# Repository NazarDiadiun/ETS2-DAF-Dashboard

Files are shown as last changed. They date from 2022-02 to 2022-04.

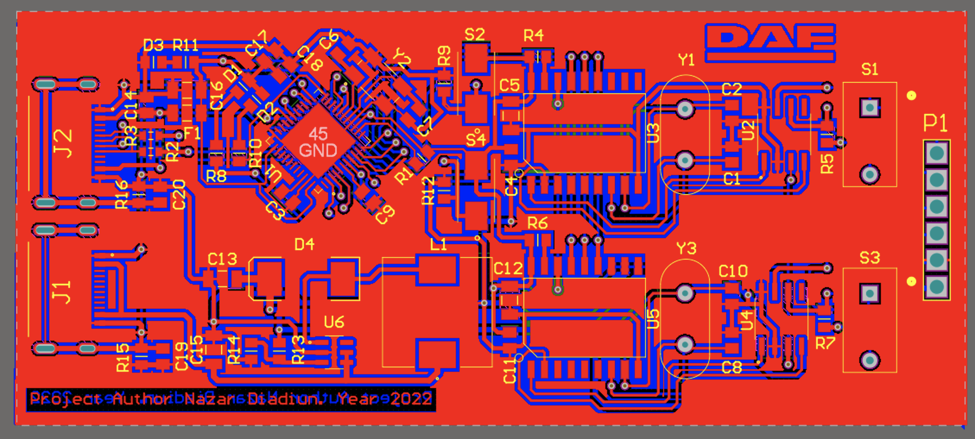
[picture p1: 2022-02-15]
Altium PCB/PCB Screenshots/PCB Front.png

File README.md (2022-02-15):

# ETS2-DAF-Dashboard

The idea of the project dates back a long time, but it was only recently that I was able to get a dashboard from a truck. As a truck fan, Euro Truck Simulator 2, and with engineering skills, I could not resist displaying telemetry from the game to the dashboard.

Gradually I will upload the project development files to share with you the experience and give the opportunity to easily repeat such project to you.

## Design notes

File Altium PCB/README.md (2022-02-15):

# PCB

The dashboard needs two CAN interfaces to function properly and fully. I decided not to invent solutions on a breadboard, but to design a printed circuit board on which I placed all the necessary components.
Project sources, archive with Gerber files, some screenshots and schematic I uploaded to this directory

## Microcontroller
The microcontroller selected ATmega32u4 as the microcontroller - it is easy to plug, supports work as a HID device and other.

## CAN Bus
CAN built on MCP2515 and TJA1050
There are switches to connect 120 Ohm resistors parallel to CAN Low and CAN High outputs

## USB
Two USB Type-C connectors are used to transfer data and power the dashboard.

## Dashboard Power
To power the dashboard it is necessary 24B, which is obtained by means of the MT3608 converter.

## Other Peripheral
Also added some buttons just in case.

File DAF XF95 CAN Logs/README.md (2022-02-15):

# CAN Bus Logs From DAF XF95

A very important part of the project was to record the logs from the truck to understand which packets to send to the dashboard.
I recorded several logs from the I-CAN bus and V-CAN bus. Both transmit data at a speed of 250KB/s.
Some work on the data packets I enclosed in the Excel files where I described what bit in the packet is responsible for.

Some very useful ones pdf files for those who are also interested in replicating the project - linked to the tachograph and its CAN bus and another - FMS standard description (commercial transport has common address for data transfer)

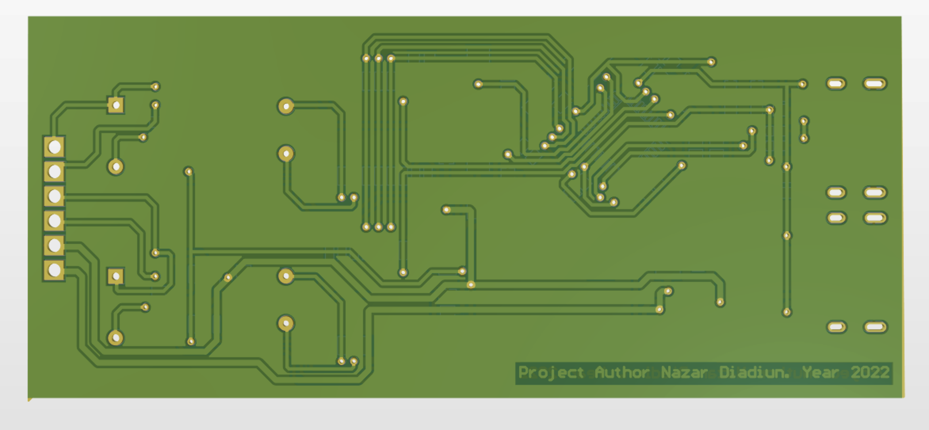
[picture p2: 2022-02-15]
Altium PCB/PCB Screenshots/PCB 3D Back.png

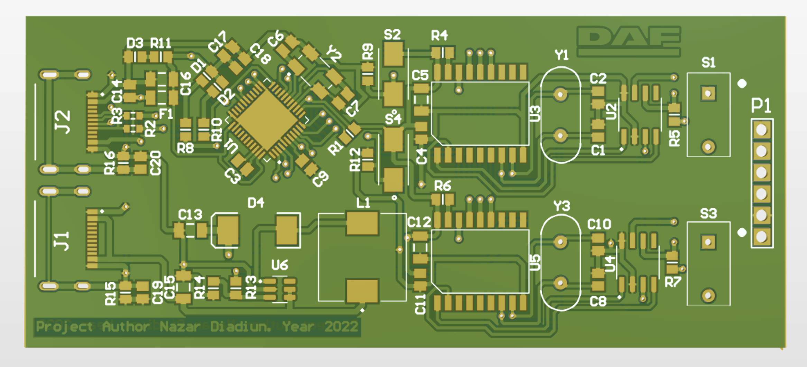
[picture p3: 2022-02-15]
Altium PCB/PCB Screenshots/PCB 3D Front.png

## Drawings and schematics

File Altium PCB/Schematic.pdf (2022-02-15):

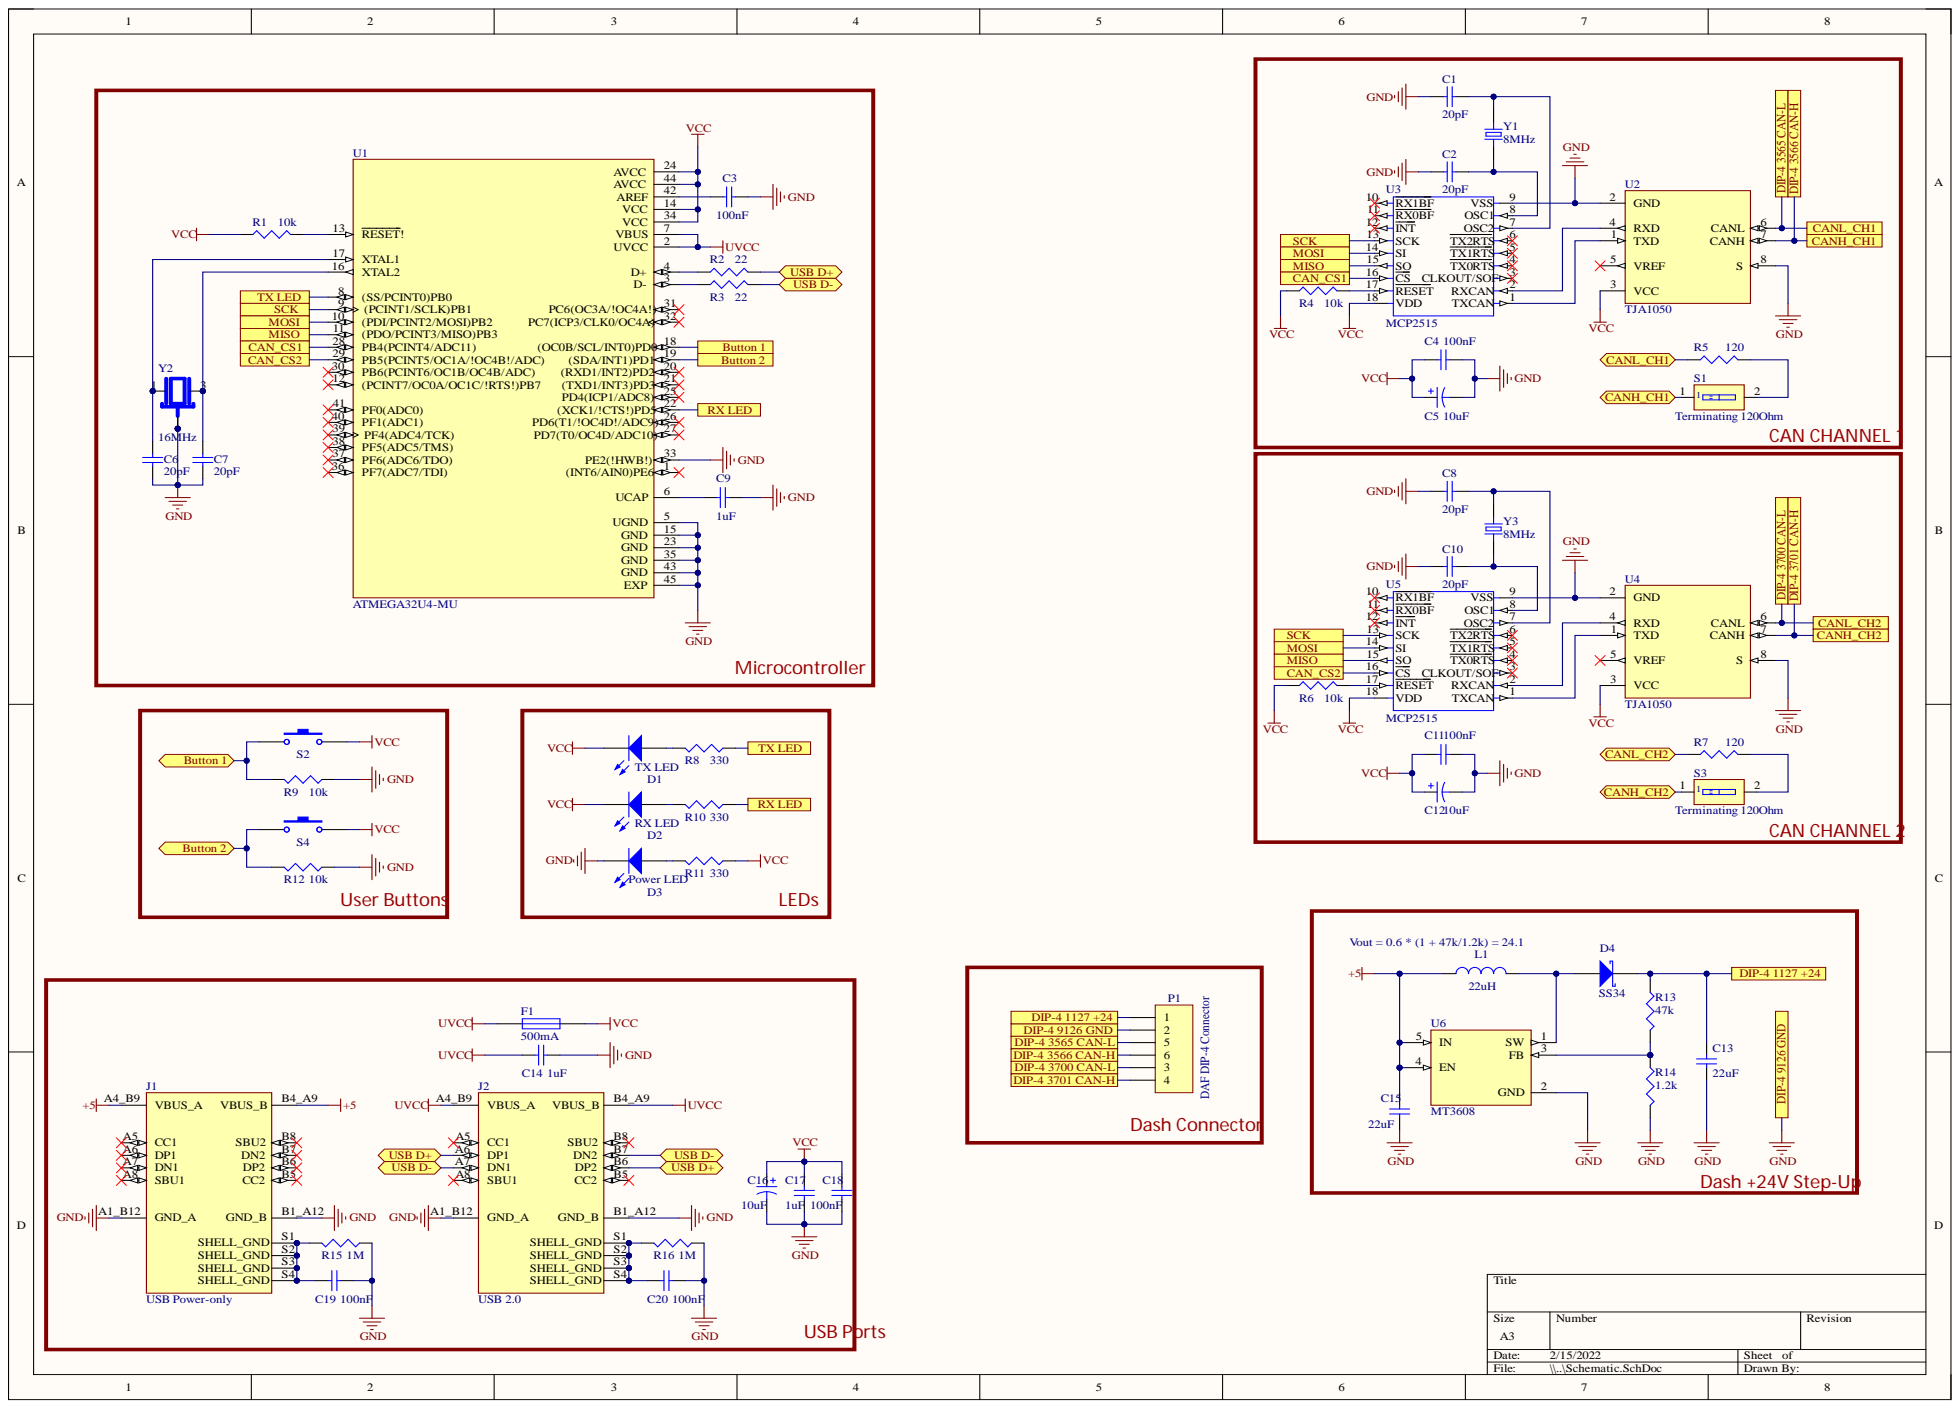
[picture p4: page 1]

DIP-4 3565 CAN-L DIP-4 3566 CAN-H DIP-4 3700 CAN-L DIP-4 3701 CAN-H

PB5(PCINT5/OC1A/!OC4B!/ADC) 29

CAN_CS2 | PB6(PCINT6/OC1B/OC4B/ADC) 30 | Button 2

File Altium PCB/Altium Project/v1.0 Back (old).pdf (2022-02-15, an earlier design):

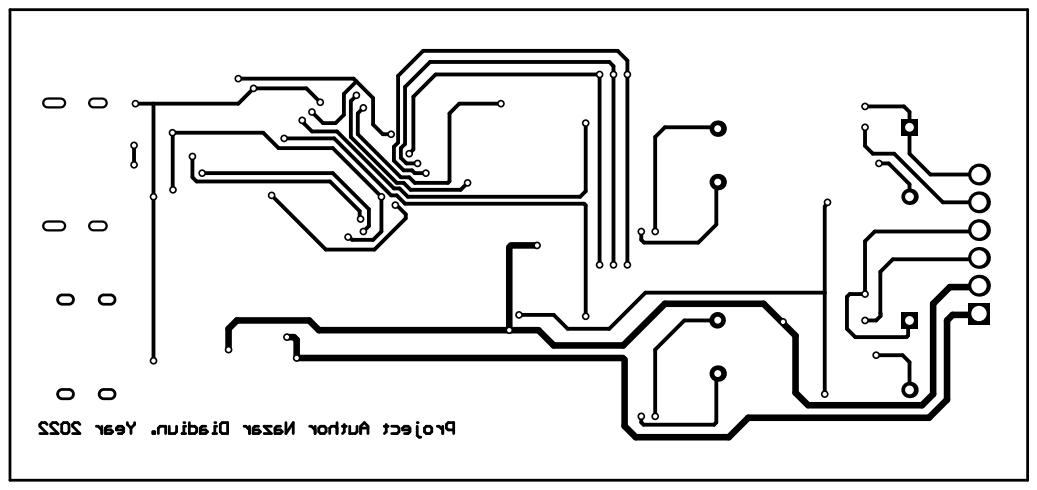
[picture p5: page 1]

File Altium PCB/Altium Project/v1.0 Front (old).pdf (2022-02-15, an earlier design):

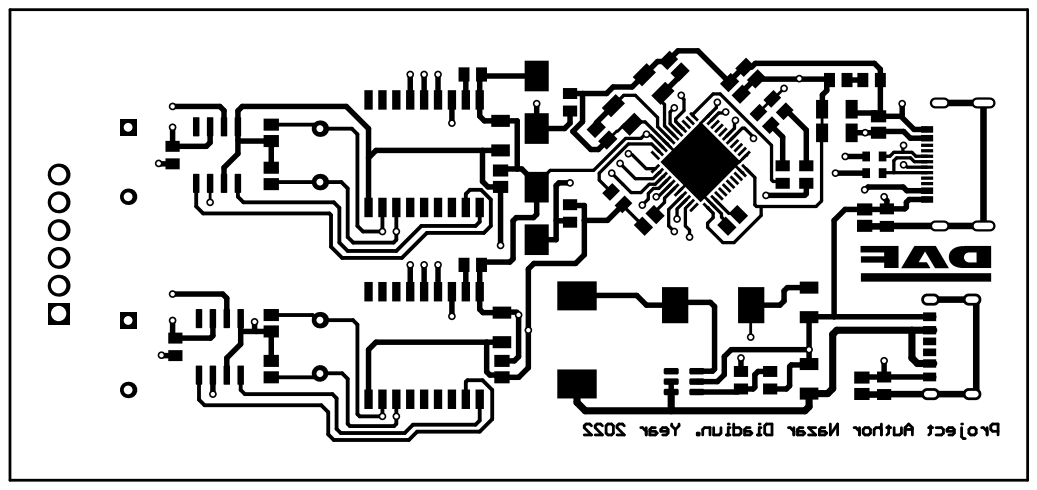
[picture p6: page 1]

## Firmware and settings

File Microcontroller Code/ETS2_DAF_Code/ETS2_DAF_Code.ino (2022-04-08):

#include <SPI.h>
#include <mcp2515.h>
#include <EEPROM.h>
#include <avr/pgmspace.h>
#include "Dashboard_Data.h"
#include "Main_Display.h"
#include "Project_Functions.h"
#include "ETS_Parse.h"

#include <TaskScheduler.h>
Scheduler DAF;

Task TS_Dashboard_Main(40, TASK_FOREVER, &Dashboard_Main_Callback);
Task TS_Right_Display(50, TASK_FOREVER, &Right_Display_Callback);
Task TS_Icons(100, TASK_FOREVER, &Icons_Callback);
Task TS_Speedometer(50, TASK_FOREVER, &Speedometer_Callback);
Task TS_RPM(50, TASK_FOREVER, &RPM_Callback);
Task TS_Distances(1000, TASK_FOREVER, &Distances_Callback);
Task TS_Arrows(50, TASK_FOREVER, &Arrows_Callback);
Task TS_Time(1000, TASK_FOREVER, &Time_Callback);
Task TS_MileageReset(500, TASK_FOREVER, &Mileage_Read_Callback);

#define I_CAN_CS 8
#define V_CAN_CS 9

MCP2515 ICAN(I_CAN_CS);
MCP2515 VCAN(V_CAN_CS);

void setup()
{
  Serial.begin(115200);
  while (!Serial) {
    ;
  }

  SPI.begin();

  ICAN.reset();
  ICAN.setBitrate(CAN_250KBPS, MCP_8MHZ);
  ICAN.setNormalMode();

  VCAN.reset();
  VCAN.setBitrate(CAN_250KBPS, MCP_8MHZ);
  VCAN.setNormalMode();




  DAF.addTask(TS_Dashboard_Main);
  TS_Dashboard_Main.enable();

  DAF.addTask(TS_Right_Display);
  TS_Right_Display.enable();

  DAF.addTask(TS_Icons);
  TS_Icons.enable();

  DAF.addTask(TS_Speedometer);
  TS_Speedometer.enable();

  DAF.addTask(TS_RPM);
  TS_RPM.enable();

  DAF.addTask(TS_Distances);
  TS_Distances.enable();

  DAF.addTask(TS_Arrows);
  TS_Arrows.enable();

  DAF.addTask(TS_Time);
  TS_Time.enable();

  DAF.addTask(TS_MileageReset);
  TS_MileageReset.enable();

  //Ignition = true;
  DisplayStartUp = true;
  DisplayActive = true;
  //EngineOn = false;

  //ToggleIcon(COOLANT_LEVEL, WARNING, 1);
  //ToggleIcon(EBS_TRUCK, ALARM, 1);
  //ToggleIcon(ENGINE, ALARM, 1);
  //ToggleIcon(ENGINE, WARNING, 1);
}

long timer2 = 0;

void loop()
{
  ParseIncoming();

  if (millis() - DisplayUpperTimer > DisplayUpperDelay && DisplayActive)
  {
    DisplayUpperFrame.can_id  = 0x18FF3527 | CAN_EFF_FLAG;
    DisplayUpperFrame.can_dlc = 8;

    FillDisplayUpperArray();

    DisplayUpperCnt++;
    if (DisplayUpperCnt > 3)
      DisplayUpperCnt = 0;

    for (byte cnt = 0; cnt < 8; cnt++)
    {
      DisplayUpperFrame.data[cnt] = DisplayUpperArray[DisplayUpperCnt][cnt];
    }

    ICAN.sendMessage(&DisplayUpperFrame);

    DisplayUpperTimer = millis();

    if (DisplayUpperCnt == 2)
      DisplayUpperDelay = 30;
    else
      DisplayUpperDelay = 10;
  }
  if (!DisplayActive)
    DisplayUpperCnt = 0;


  if (millis() - timer2 > 700)
  {
    timer2 = millis();
    counter++;
    //Speed = counter;
    //CruiseControl = counter;
    //DisplayTurbo[0][4] = counter;

    //Serial.println(counter, HEX);
  }

  /* Text mode icons
     0х10 чувак
     трасса км
     трасса мол
     трасса
     спальник
     сервис
     часи
     фура
     работа
     руль
     заправка

  */

  if (millis() - DisplayStratupTimer > DisplayStratupDelay && DisplayStartUp)
  {
    if (DisplayPage < 2 || DisplayPage == 2 && DisplayStartupIconCnt == 9)
      DisplayPage++;

    if (DisplayPage == 1)
    {
      if (DisplayAlarmCount != 0 || DisplayWarningsCount != 0)
      {
        DisplayStartupStage1_FillArray(); // Filling up 3727 Array
        DisplayCnt = 0;
        DisplayArraySize = 3;

        DisplayStratupTimer = millis();
        DisplayStratupDelay = 3000;
      }
      else
        DisplayStratupDelay = 0;
    }
    else if (DisplayPage == 2) // Showing warnings one by one with 4 sec duration for each
    {
      DisplayCnt = 0;
      DisplayArraySize = 7;

      byte IconID = DisplayIcons[DisplayStartupIconCnt];
      if (IconID != 0 && IconID != 1 && IconID != 7)
      {
        Serial.println(IconID);
        // Copying message to buffer
        if (DisplayStartupIconCnt < 3) // Alarms
          DisplayIconMessage_FillArray(IconID, ALARM);
        else // Warnings
          DisplayIconMessage_FillArray(IconID, WARNING);

        DisplayStratupDelay = 4000;
      }
      else
        DisplayStratupDelay = 0;

      DisplayStartupIconCnt++;
      DisplayStratupTimer = millis();
    }
    else if (DisplayPage == 3)
    {
      DisplayCnt = 0;
      DisplayArraySize = 8;

      DisplayStartUp = false;
      DisplayStartupIconCnt = 0;
    }
  }

  if (millis() - DispTimer > 10)
  {
    DisplayOther.can_id  = 0x18FF3727 | CAN_EFF_FLAG;
    DisplayOther.can_dlc = 8;

    DisplayCnt++;
    if (DisplayCnt > DisplayArraySize - 1)
      DisplayCnt = 0;

    for (byte cnt = 0; cnt < 8; cnt++)
    {
      if (DisplayPage == 1)
        DisplayOther.data[cnt] = DisplayStartupStage1[DisplayCnt][cnt];
      else if (DisplayPage == 2)
        DisplayOther.data[cnt] = DisplayStartupStage2[DisplayCnt][cnt];
      else
      {
        if (DispPage == 0)
        {
          DisplayOther.data[cnt] = pgm_read_byte(&DisplayBlank[DisplayCnt][cnt]);
        }
        else if (DispPage == 1)
        {
          DisplayFuelUsage_FillArray();
          DisplayOther.data[cnt] = DisplayFuelUsage[DisplayCnt][cnt];
        }
        else if (DispPage == 2)
        {
          DisplayFuelInfo_FillArray();
          DisplayOther.data[cnt] = DisplayFuelInfo[DisplayCnt][cnt];
        }
        else if (DispPage == 3)
        {
          DisplayOther.data[cnt] = DisplayTurbo[DisplayCnt][cnt];
        }
        else if (DispPage == 4)
        {
          DisplaySpeedInfo_FillArray();
          DisplayOther.data[cnt] = DisplaySpeedInfo[DisplayCnt][cnt];
        }
        else if (DispPage == 5)
        {
          DisplayTemperature_FillArray();
          DisplayOther.data[cnt] = DisplayTemperature[DisplayCnt][cnt];
        }
      }
    }

    ICAN.sendMessage(&DisplayOther);
    DispTimer = millis();
  }

  DAF.execute();
}

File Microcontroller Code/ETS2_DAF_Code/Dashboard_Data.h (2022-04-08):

bool GamePaused = false;
byte TimeHours = 0; // Часы
byte TimeMinutes = 0; // Минуты
int NextRest = 0; // Time for next rest stop

// Truck Variables
float Speed = 0.0; // Скорость автомобиля
float EngineSpeed = 0; // Обороты двигателя
int FuelCapacity = 0; // Fuel tank capacity
int FuelAmount = 0; // Amount of fuel in tank
int Range = 0; // Range in km on estimated fuel
int AvFuelCons = 0; // Average Fuel Consumption x 10
int AdBlueCapacity = 0; // Adblue tank capacity
int AdBlueAmount = 0; // Adblue current amount
int OilPressure = 0; // Oil Pressure Value in psi
int OilTemperature = 0; // Oil Temperautre Value int Celcius
int WaterTemperature = 0; // Температура охл. жидкости
int AirPressure = 0; // Air Pressure Value in psi
float BatteryVoltage = 0; // Battery Voltage Value * 10 in Volts (245 = 24.5V)
int CruiseControl = 0; // Cruise control speed (0 if disabled)
int Gear = 0; // Current gear
int EffectiveThrottle = 0; // Current Effective Throtle Value 0 - 100%
int BrakesTemperature = 0; // Current Brakes tempereature in Celsius
bool Ignition = false; // ignition on flag
bool EngineOn = false; // Engine on flag
bool TrailerConnected = false;
float Distance = 0.0; // Общий пробег
int SpeedLimit = 0; // Current Speed limit on road

// Other computed values
float DistanceDaily = 0.0; // Суточный пробег
float DistanceEEPROM = 0.0;


int Fuel = 0, Air1 = 0, Air2 = 0, AdBlue = 0;

// Warnings
bool LowOilPressure = false;
bool LowBattery = false;
bool AirPressureWarning = false;
bool AirPressureEmergency = false;
bool WaterTempWarning = false;
bool IndicatorLowFuel = false;
bool LowAdBlue = false;

// Warnings
bool IconParkingBrake = false;
bool IconLeftTruck = false;
bool IconRightTruck = false;
bool LightParking = false;
bool IconLowBeam = false;
bool IconHighBeam = false;
// Beacon lights
bool IconRetarder = false;
bool IconAxisBlock = false;

byte EngineWear = 0, TransmissionWear = 0, CabinWear = 0, ChassisWear = 0, WheelsWear = 0;


byte Dashboard_Backlight = 100; // Яркость подсветки приборной панели (стрелки, шкалы)
byte MiniDisplays_Backlight = 100; // Яркость подстветки экранчиков (время, пробег)
byte Icons_Backlight = 100; // Яркость подсветки иконок
byte Sound_Loudness = 70; // Громкость звукового сигнала

float OutsideTemperature = 18.0; // Температура воздуха снаружи

// 500ms blinker

bool IndicatorTacho = false;

bool IconLeftTrailer = false;
bool IconRightTrailer = false;
bool IconStop = false;
bool IconFogFront = false;
bool IconFogRear = false;
bool IconLowGear = false;
bool IconPTO = false;
bool IconCoil = false;
bool IconWindowCycleArrow = false;
bool IconASR = false;
bool IconTrailerAbs = false;
bool IconWorkLight = false;
bool IconChassisTransport = false;

bool SoundBlinker = false;
bool SoundWarnOnce = false;
bool SoundAlarmOnce = false;
bool SoundAlarmCont = false;

int DispPage = 0; // Current Info Page Displayed
byte DisplayActive = false;
byte DisplayAlarmCount = 0;
byte DisplayWarningsCount = 0;

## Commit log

2022-02-15 First Commit!
    - Added Altium PCB Project sources
    - DAF XF95 Truck CAN logs and other documentation
    - Created README files with directories description
    [DAF CAN Bus.xlsx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]
2022-02-17 Dashboard Display Features
    - Python script URL changed to Telemetry API Local Address
    - Display now working with minimal functionality, but at least, it works!
    - Current Gear (R, N, D)
    - Functions to toggle any of available icons on display (declared)
    - while engine is not running - low oil pressure and battery (by telemetry parameters)
    - Warnings and alarms count on display (example, when oil and battery is displaying - 2 red messages on display)
    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
